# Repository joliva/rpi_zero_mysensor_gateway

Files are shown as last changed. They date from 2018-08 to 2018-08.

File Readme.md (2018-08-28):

More details: https://www.thingiverse.com/thing:3072244

# Summary
Raspberry Pi Zero W based MySensor controller/gateway with Long Range NRF24L01 + PA + LNA RF Transceiver.

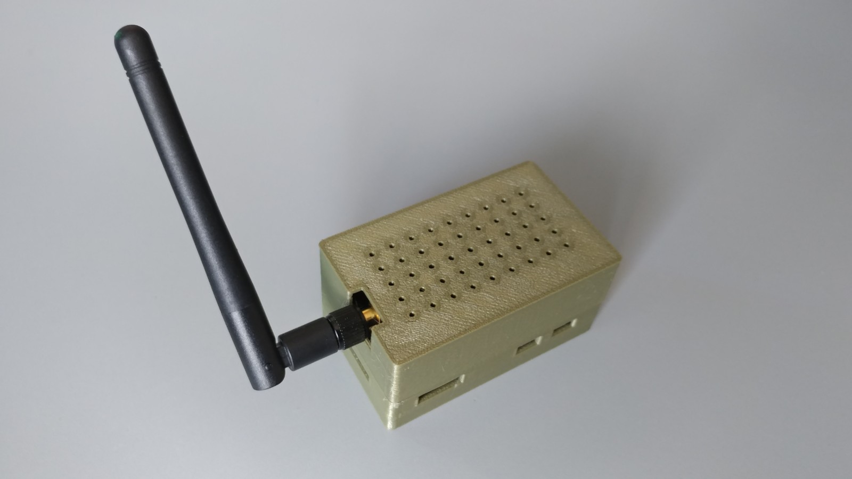
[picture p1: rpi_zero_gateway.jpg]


# Attribution
Based off Jumbospot / Zumspot Raspberry Pi Zero Wireless Case by Plankto. https://www.thingiverse.com/thing:2773755

# Usage
Created with OpenSCAD 

1. Print the 3 parts
2. Increase existing rPi Zero mounting holes to 3mm (e.g. drill them carefully)
3. Insert the Pi into the lower piece
4. Attach Long Range NRF24L01 + PA + LNA RF Transceiver to the insert (e.g. super glue)
5. Wire the radio (NRF24L01) to the rPI zero header
6. Press the insert onto the rPI zero
7. Install M3x25 screws through bottom, insert, and finally into the top
8. Configure MySensor gateway according to: https://www.mysensors.org/build/raspberry
9. Optional: Add controller code to rPI according to: https://www.mysensors.org/controller

# Print Settings

* Printer: Prusa MK3
* Rafts: No
* Supports: No
* Resolution: 0.2mm
* Infill: 20%

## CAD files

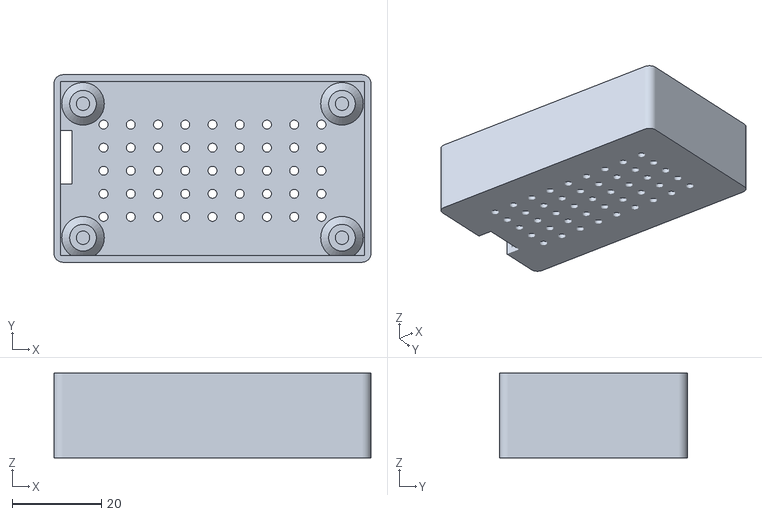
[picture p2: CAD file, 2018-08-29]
generated/rpi_zero_case_top.stl
71.0 x 42.0 x 19.0

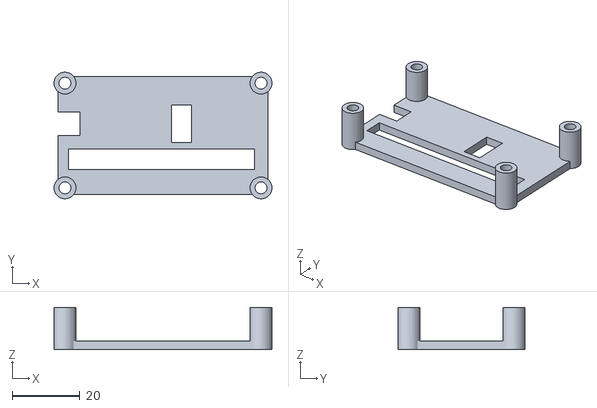
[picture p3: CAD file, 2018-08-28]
generated/rpi_zero_case_insert.stl
64.5 x 37.5 x 12.5

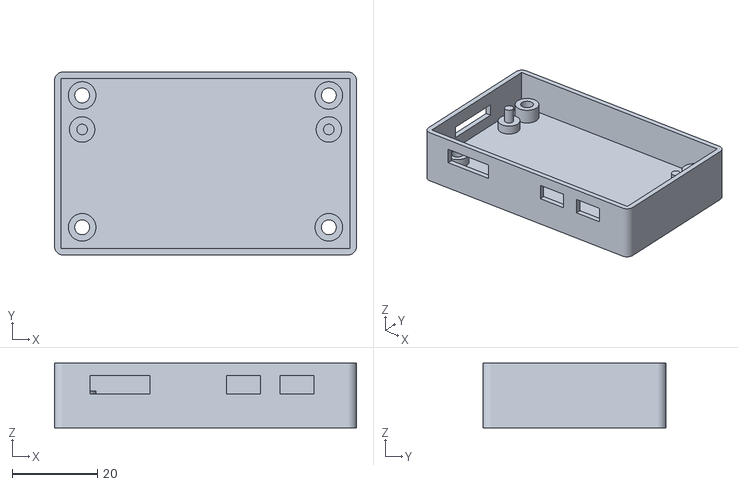
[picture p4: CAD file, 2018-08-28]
generated/rpi_zero_case_bottom.stl
71.0 x 43.0 x 15.2

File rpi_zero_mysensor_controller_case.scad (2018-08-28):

/* 
*  Open SCAD Name.: rpi_zero_mysensor_controller_case.scad
*  Copyright (c)..: 2018 John Oliva
*
*  Creation Date..: 08/20/2018
*  Last Modified..: 08/24/2018
*  Description....: Contact sensor housing
*  Version........: 1.0
*
*  Built On: Open SCAD version 2018.03.17
*
*  Attribution: based on Jumbospot / Zumspot Raspberry Pi Zero Wireless Case 
                https://www.thingiverse.com/thing:2773755, by Plankto
*
*  LICENSE:
*  
*  MIT License (https://opensource.org/licenses/MIT)
*  
*  THE SOFTWARE IS PROVIDED "AS IS", WITHOUT WARRANTY OF ANY KIND, EXPRESS OR IMPLIED, 
*  INCLUDING BUT NOT LIMITED TO THE WARRANTIES OF MERCHANTABILITY, FITNESS FOR A PARTICULAR 
*  PURPOSE AND NONINFRINGEMENT. IN NO EVENT SHALL THE AUTHORS OR COPYRIGHT HOLDERS BE LIABLE 
*  FOR ANY CLAIM, DAMAGES OR OTHER LIABILITY, WHETHER IN AN ACTION OF CONTRACT, TORT OR 
*  OTHERWISE, ARISING FROM, OUT OF OR IN CONNECTION WITH THE SOFTWARE OR THE USE OR OTHER 
*  DEALINGS IN THE SOFTWARE.
*/ 

PI_TOL_X = 1.0*1;
PI_TOL_Y = 1.0*1;
EXTWID = 0.5*1;                     // extrusion width
WALL = 3 * EXTWID;

WIDTH = 42;
WIDTH_ADJ = WIDTH + PI_TOL_Y;
LENGTH = 69 + 2*PI_TOL_X;
HEIGHT = 12*1;
TOP_HEIGHT = 19.0;

SCREW_DIAM = 3.0*1;

HOLE_RAD = SCREW_DIAM/2;
HOLE_PASS_RAD = (SCREW_DIAM + EXTWID)/2;

IPOST_RAD = (SCREW_DIAM - EXTWID)/2 ;
OPOST_RAD = HOLE_RAD + 3*EXTWID;
OPOST_PASS_RAD = HOLE_PASS_RAD + 3*EXTWID;

INSERT_POST_HEIGHT = 12.5*1;

RPI_THICK = 1.5*1;
SCREW_HEAD = 3 + .2;

FN_LOW = 32;
FN_HIGH = 50;

// Configuration
CONFIG = "flat";  // ["flat", "assembled", "none"]

// Show Bottom
SHOW_BOT = true;

// Show Top
SHOW_TOP = true;

// Show Insert
SHOW_INSERT = true;

// Add ventilation
VENT = true;

// Display RPI
SHOW_RPI = true;

// Display nRF24L01
SHOW_RADIO = true;

if (CONFIG == "flat") {
   if (SHOW_BOT) {
      bottom();
   }

   if (SHOW_TOP) {
      translate([73,0,0]) top(); 
   }

   if (SHOW_INSERT) {
      translate([0,WIDTH_ADJ,0]) insert();
   }
}

if (CONFIG == "assembled") { 
   if (SHOW_BOT) {
      bottom();
   }

   if (SHOW_TOP) {
      translate([0,WIDTH_ADJ,HEIGHT+TOP_HEIGHT+SCREW_HEAD])
         rotate([180,0,0]) 
            top();
   }

   if (SHOW_INSERT) {
      translate([PI_TOL_X,WIDTH_ADJ+PI_TOL_Y,11+4+RPI_THICK+SCREW_HEAD])
         rotate([180,0,0]) 
            insert();
   }

   if (SHOW_RPI == true) {
      translate([PI_TOL_X,PI_TOL_Y,SCREW_HEAD])
         color("indianred", alpha=1) RPI();
   }

   if (SHOW_RADIO == true) {
      translate([PI_TOL_X,PI_TOL_Y,SCREW_HEAD])
         color("turquoise", alpha=1) Radio();
   }
}

module bottom(){
   difference() {
	   union() {
		   cube([LENGTH,WIDTH_ADJ,SCREW_HEAD]);   // additional base to accomodate screw head
	
		   translate([0,0,SCREW_HEAD]) {
		      difference(){
		         //lower casing
		         cube([LENGTH,WIDTH_ADJ,HEIGHT]);
		  
		         union(){
		            //lower casing
		            translate([WALL,WALL,WALL])cube([LENGTH-2*WALL,WIDTH_ADJ-2*WALL,HEIGHT]);
		          
		            //hdmi port 
		            translate([7.4+PI_TOL_X,-1,4.8])cube([14,5,4.25]);
		              
		            //usb port 1
		            translate([39.4+PI_TOL_X,-1,4.8])cube([8,5,4.25]);
		          
		            //usb port 2
		            translate([52+PI_TOL_X,-1,4.8])cube([8,5,4.25]);
		          
		            //SD card
		            translate([-1,11.15+PI_TOL_Y,4.8])cube([5,15.5,3.3]);
		          
		            //top
		            translate([0,WIDTH_ADJ,HEIGHT+TOP_HEIGHT])
		               rotate([180,0,0]) 
		                  top();
		          }
		      }
		  
		      //mounting posts
		      translate([5.5+PI_TOL_X,5.5+PI_TOL_Y,0]) cylinder(r=OPOST_PASS_RAD, h=4, $fn=FN_LOW);
		      translate([63.5+PI_TOL_X,5.5+PI_TOL_Y,0]) cylinder(r=OPOST_PASS_RAD, h=4, $fn=FN_LOW);
		      translate([5.5+PI_TOL_X,WIDTH_ADJ-6.5+PI_TOL_Y,0]) cylinder(r=OPOST_PASS_RAD, h=4+RPI_THICK, $fn=FN_LOW);
		      translate([63.5+PI_TOL_X,WIDTH_ADJ-6.5+PI_TOL_Y,0]) cylinder(r=OPOST_PASS_RAD, h=4+RPI_THICK, $fn=FN_LOW);
		
		      translate([5.5+PI_TOL_X,28.5+PI_TOL_Y,0]) cylinder(r=OPOST_RAD, h=4, $fn=FN_LOW);
		      translate([63.5+PI_TOL_X,28.5+PI_TOL_Y,0]) cylinder(r=OPOST_RAD, h=4, $fn=FN_LOW);
		      translate([5.5+PI_TOL_X,28.5+PI_TOL_Y,0]) cylinder(r=IPOST_RAD, h=8, $fn=FN_HIGH);
		      translate([63.5+PI_TOL_X,28.5+PI_TOL_Y,0]) cylinder(r=IPOST_RAD, h=8, $fn=FN_HIGH);
		   }
	   }

	   union() {
		   //fillet
		   translate([0,0,-.001]) fillet(2, 30+1);
		   translate([LENGTH,0,-.001])rotate([0,0,90])fillet(2, 30+1);
		   translate([0,WIDTH_ADJ,-.001])rotate([0,0,-90])fillet(2, 30+1);
		   translate([LENGTH,WIDTH_ADJ,-.001])rotate([0,0,180])fillet(2, 30+1);
	
	      // screws
	      translate([5.5+PI_TOL_X,5.5+PI_TOL_Y,-.001]) M3x(length_mm=10, add_tol=true);
	      translate([63.5+PI_TOL_X,5.5+PI_TOL_Y,-.001]) M3x(length_mm=10, add_tol=true);
	      translate([5.5+PI_TOL_X,WIDTH_ADJ-6.5+PI_TOL_Y,-.001]) M3x(length_mm=10, add_tol=true);
	      translate([63.5+PI_TOL_X,WIDTH_ADJ-6.5+PI_TOL_Y,-.001]) M3x(length_mm=10, add_tol=true);
	   }
   }
}

module top(){
    W = WIDTH_ADJ - 5.5;

    H_POST = 13;

    difference() {
        union() {
            // shell
            difference() {
               //upper casing
               cube([LENGTH,WIDTH_ADJ,TOP_HEIGHT]);

               translate([WALL,WALL,WALL])cube([LENGTH-2*WALL,WIDTH_ADJ-2*WALL,TOP_HEIGHT]);
            }

            //mounting posts
            translate([5.5+PI_TOL_X,5.5,0])cylinder(r=OPOST_RAD, h=H_POST, $fn=FN_LOW);
            translate([63.5+PI_TOL_X,5.5,0])cylinder(r=OPOST_RAD, h=H_POST, $fn=FN_LOW);
            translate([5.5+PI_TOL_X,W-PI_TOL_Y,0])cylinder(r=OPOST_RAD, h=H_POST, $fn=FN_LOW);
            translate([63.5+PI_TOL_X,W-PI_TOL_Y,0])cylinder(r=OPOST_RAD, h=H_POST, $fn=FN_LOW);
        }
    
        union() {
            // antenna connector hole
            translate([-.001,W-19,-.001]) cube([4,12,TOP_HEIGHT-8]);
        
            //fillet
            fillet_len = 2*TOP_HEIGHT;
            fillet(2, fillet_len);
            translate([LENGTH,0,0])rotate([0,0,90])fillet(2, fillet_len);
            translate([0,WIDTH_ADJ,0])rotate([0,0,-90])fillet(2, fillet_len);
            translate([LENGTH,WIDTH_ADJ,0])rotate([0,0,180])fillet(2, fillet_len);

            // screw holes
            translate([5.5+PI_TOL_X,5.5,2*WALL]) cylinder(r=HOLE_RAD, h=H_POST, $fn=FN_HIGH);
            translate([63.5+PI_TOL_X,5.5,2*WALL]) cylinder(r=HOLE_RAD, h=H_POST, $fn=FN_HIGH);
            translate([5.5+PI_TOL_X,W-PI_TOL_Y,2*WALL]) cylinder(r=HOLE_RAD, h=H_POST, $fn=FN_HIGH);
            translate([63.5+PI_TOL_X,W-PI_TOL_Y,2*WALL]) cylinder(r=HOLE_RAD, h=H_POST, $fn=FN_HIGH);

            // ventilation
            if (VENT) {
	            OFFSET = 5;
	            NX = 9;
	            NY = 5;
	            DX = (LENGTH - 2*OFFSET)/(NX+1);
	            DY = (WIDTH - 2*OFFSET)/(NY+1);
	            for (x = [1:NX]) {
	               for (y = [1:NY]) {
	                  translate([OFFSET+x*DX,OFFSET+y*DY,0]) cylinder(d=2, h=3*WALL, center=true, $fn=FN_HIGH);
	               }
	            }
            }
        }
    }
}

module insert(){
    W = WIDTH_ADJ - 7;

    translate([0,0,-(INSERT_POST_HEIGHT-11)])
    difference(){
        union(){
            //mounting posts
            translate([5.5,6.5,0]) cylinder(r=OPOST_PASS_RAD, h=INSERT_POST_HEIGHT, $fn=FN_LOW);
            translate([63.5,6.5,0]) cylinder(r=OPOST_PASS_RAD, h=INSERT_POST_HEIGHT, $fn=FN_LOW);
            translate([5.5,WIDTH_ADJ-5.5,0]) cylinder(r=OPOST_PASS_RAD, h=INSERT_POST_HEIGHT, $fn=FN_LOW);
            translate([63.5,WIDTH_ADJ-5.5,0]) cylinder(r=OPOST_PASS_RAD, h=INSERT_POST_HEIGHT, $fn=FN_LOW);
            
            translate([3.5,4.5,0]) cube([62,W-1,2.5]);  
        }

        union(){
            translate([3,W-14,-.001]) cube([7,7,4.0]);  // cut-out for radio antenna connector
            translate([37,W-16,-.001]) cube([6,11,3.5]);  // cut-out for radio board connector
            translate([34,W-21,1.5]) cube([55,6,4], center=true);  // cut-out for access to RPI header

            //holes
            translate([5.5,6.5,-1])cylinder(r=HOLE_PASS_RAD, h=INSERT_POST_HEIGHT+2, $fn=FN_HIGH);
            translate([63.5,6.5,-1])cylinder(r=HOLE_PASS_RAD, h=INSERT_POST_HEIGHT+2, $fn=FN_HIGH);
            translate([5.5,WIDTH_ADJ-5.5,-1])cylinder(r=HOLE_PASS_RAD, h=INSERT_POST_HEIGHT+2, $fn=FN_HIGH);
            translate([63.5,WIDTH_ADJ-5.5,-1])cylinder(r=HOLE_PASS_RAD, h=INSERT_POST_HEIGHT+2, $fn=FN_HIGH);
        }
    }
}

module RPI() {
   translate([65/2+2,30/2+2,4]) 
   union() {
      translate([0,11.3,10/2]) cube([53,3,10], center=true);  // header
      translate([-5.5,-2,5.2]) cube([14,14,5],center=true);  // heatsink
      import("rpi_zero_model.stl");
   }
}

module Radio() {
   translate([3,10,18])
   union() {
      cube([40,15,1]);  // board
      translate([35,3,-8.5]) cube([4,9,8.5]);  // board connector
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

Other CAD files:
rpi_zero_mysensor_gateway.scad

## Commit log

2018-08-24 Safety commit pre-changing to 0.5mm resolution.
    [rpi_zero_model.stl]
2018-08-27 Cleaned up code. Added vent holes to top. Changed extrusion width to 0.5mm and all dimensions based on that to be integral multiples.
    [rpi_zero_case.scad]
2018-08-27 Renamed file to be more meaningful.
    [rpi_zero_mysensor_controller_case.scad]
2018-08-27 Don't want the STL file stored with the source.
    [rpi_zero_model.stl]
2018-08-28 Added license to source.
    [rpi_zero_mysensor_controller_case.scad]
2018-08-28 V1 STl files.
    [rpi_zero_case_bottom.stl, rpi_zero_case_insert.stl, rpi_zero_case_top.stl]
2018-08-28 Renamed to more accurately reflect use.
    [rpi_zero_mysensor_gateway.scad]
2018-08-28 Picture of completed enclosure.
2018-08-28 Added photo of completed enclosure.
2018-08-28 Added a couple of other build instructions.
2018-08-28 Added build step - increase rPi Zero mounting holes.
2018-08-29 Strengthen posts on top post by added chamfer.
    [rpi_zero_case_top.stl, rpi_zero_mysensor_gateway.scad]
